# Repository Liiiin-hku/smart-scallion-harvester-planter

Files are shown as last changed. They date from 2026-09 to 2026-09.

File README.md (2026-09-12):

# 智能大葱收种一体机
# Smart Scallion Harvester–Planter

**机械结构设计作品集 · Mechanical Design Portfolio**

围绕大葱收获与种植作业的一体化机械方案，展示整机布局、型材车架、扶葱输送、弹簧张紧、翻土开沟及播种机构的 SOLIDWORKS 零件与装配设计。

A mechanical design concept integrating scallion harvesting and planting operations, with native SOLIDWORKS models covering the overall layout, profile frame, crop-guiding conveyors, spring tensioning, soil-working tools and planting mechanism.

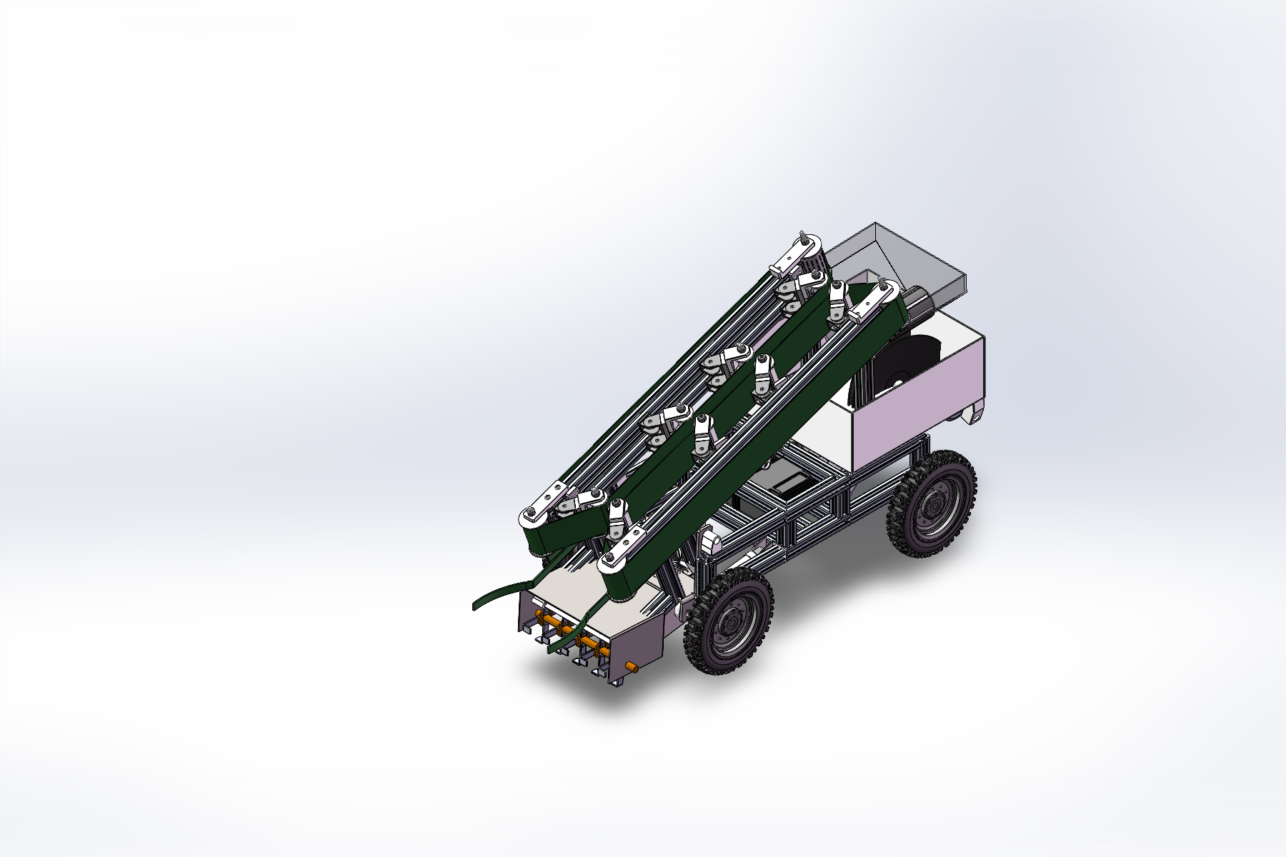
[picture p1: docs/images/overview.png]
整机等轴测视图 / Overall isometric view


> 图像直接导自本仓库模型的 SOLIDWORKS 视图。仓库定位为机械 CAD 设计展示；“智能”沿用项目概念名称，本次发布不包含控制程序、自动导航或田间试验数据。
>
> Images are exported directly from the repository's CAD models in SOLIDWORKS. This is a mechanical CAD portfolio. “Smart” is part of the project concept name; this release contains no control software, autonomous navigation implementation or field-test data.

**快速入口 / Quick links:** [机构详解 / Design walkthrough](docs/mechanical-design.md) · [模型打开指南 / Model guide](docs/model-guide.md) · [文件清单 / Inventory](docs/model-inventory.csv) · [核验记录 / Verification](docs/verification.md)

## 中文介绍

### 项目背景与方案

本项目围绕大葱收获、输送收集和种植相关作业，建立了一套共用移动底盘的机械结构方案。设计以型材车架为承载基础，将倾斜布置的收割输送组件、收集装置、翻土组件和播种组件整合到同一总装中，便于考察各机构的空间关系与安装接口。

机械设计重点在于作物流转路径与结构布置的协调：前端扶葱件与松土铲刀对应作物导入和根部松土位置；两侧输送带及导向滚轮形成向上输送通道；轴固定座、可调座、弹簧座和铰链构成滚轮支承与张紧调节结构；车架上的气缸和安装座提供作业组件的连接与调节接口。播种侧包含储存箱、播苗盘、圆盘、支撑型材及负重轮，翻土侧包含轴、翻土件、开沟件及起垄件。

最终交付是一套可查看整机及主要子机构的三维 CAD 模型，并保留 STEP 交换文件和已有工程图。设计意图依据实际零件、装配关系与可见几何说明；夹持力、张紧力、播种间距、工作效率及土壤适应性尚无本仓库内的试验数据支持。

### 建议技术读者重点查看

| 设计主题 | 模型中的具体内容 | 查看入口 |
| --- | --- | --- |
| 整机与承载结构 | 四轮布置、型材车架、横梁及多个机构安装位置 | `大葱收割机.SLDASM`、`车架.SLDPRT` |
| 扶葱与输送 | 扶葱/镜向扶葱、两侧倾斜输送带、多个导向滚轮、清土刷轮、松土铲刀 | `收割部分.SLDASM` |
| 滚轮支承与张紧 | 轴固定座、可调座、弹簧与弹簧座、活动铰链 | `输送带导向轮*.SLDASM` |
| 播种机构 | 储存箱、播苗盘、圆盘、支撑件、负重轮 | `播种部分.SLDASM` |
| 土壤作业机构 | 翻土、开沟、起垄件与共用轴的布置 | `翻土.SLDASM` |
| 装配接口 | 气缸及其安装座、轮组、轴承与标准紧固件 | 总装及配套子目录 |

## English overview

### Context and mechanical concept

This project develops a shared mobile platform for a scallion harvesting and planting concept. A frame built from structural profiles supports an inclined harvesting/conveying assembly, a collection unit, a soil-working assembly and a planting assembly. The CAD package lets reviewers examine how these mechanisms fit together and connect to the chassis.

The main design theme is the coordination of the crop path and mechanical layout. Front crop guides and soil-loosening blades define the entry region. Paired inclined belts and guide rollers form an upward conveying path. Shaft supports, adjustable mounts, spring seats and hinges form the roller-support and tensioning arrangement. Pneumatic cylinders and their mounting brackets provide mechanical connection and adjustment interfaces. The planting assembly includes a storage hopper, a planting drum/disc arrangement, supporting profiles and support wheels. The soil-working assembly includes a shaft with tilling, furrow-opening and ridging elements.

The deliverable is a three-dimensional CAD package for reviewing the complete machine and its main mechanisms, together with existing STEP exchange files and engineering drawings. Functional descriptions express design intent inferred from the actual parts, assembly relationships and visible geometry. Grip force, belt tension, planting spacing, throughput and soil performance have not been established by test data in this repository.

### Suggested technical review

Start with the overall layout and chassis interfaces, then inspect the crop-guiding conveyors, roller support and spring tensioning details. Continue with the planting and soil-working assemblies. The [illustrated walkthrough](docs/mechanical-design.md) maps these topics to exact filenames and explains the observed features in both languages.

## 获取与打开 / Download and open

1. 下载仓库完整 ZIP 并全部解压，或使用下方 Git 命令。Download and extract the entire repository ZIP, or clone it using the command below.
2. 用 SOLIDWORKS 打开 `cad/大葱收种一体机/大葱收割机.SLDASM`。Open this file as the main assembly in SOLIDWORKS.
3. 保留模型目录内的文件名和子目录。需要通用格式时可打开同目录的 `大葱收割机.STEP`。Preserve all filenames and subfolders. Use the existing `大葱收割机.STEP` for neutral-format viewing.

```bash
git clone https://github.com/Liiiin-hku/smart-scallion-harvester-planter.git
```

原模型目录完整保留，共 **217 个文件**：**86 个零件、18 个装配体、3 个工程图、110 个 STEP 文件**，合计 **221,436,406 字节（约 211.18 MiB）**。无需 Git LFS。文件数量不等于装配中的组件实例数量。

The original CAD directory is preserved with **217 files: 86 parts, 18 assemblies, 3 drawings and 110 STEP files**, totaling **221,436,406 bytes (approximately 211.18 MiB)**. Git LFS is not required. File counts differ from component-instance counts in an assembly.

## 版本与查看状态 / Version and viewing status

已在 **SOLIDWORKS 2025 SP3.0** 中只读打开总装与主要子机构并导出展示图。当前总装配置读取到 **346 个组件实例**，均为完全解析状态；其中 2 个实例来自同一个内嵌虚拟零件。总装引用链中的外部模型均位于本包内。

The main assembly and selected mechanisms were opened read-only in **SOLIDWORKS 2025 SP3.0** and used to export the illustrations. The active top-level configuration contains **346 fully resolved component instances**, including two instances of one embedded virtual part. External models in the main assembly's dependency chain resolve within this package.

两个历史工程图及八个镜向铰链装配存在缺失引用，详见[模型指南](docs/model-guide.md#known-reference-gaps)。模型内容未作修复、改名、格式升级或重新保存。已有 STEP 文件未重新生成，不承诺与原生模型逐实体一致。

Two historical drawings and eight mirrored-hinge assemblies have missing references, detailed in the [model guide](docs/model-guide.md#known-reference-gaps). Native CAD content has not been repaired, renamed, upgraded or resaved. Existing STEP files have not been regenerated or checked for entity-by-entity equivalence with the native models.

## 仓库结构 / Repository structure

```text
.
├── README.md                    # 中英文项目介绍 / Bilingual introduction
├── LICENSE                      # CERN-OHL-P-2.0
├── NOTICE.md                    # 许可范围与来源说明 / Scope and provenance
├── cad/
│   └── 大葱收种一体机/           # 原文件名、目录及内容 / Preserved CAD package
│       ├── 大葱收割机.SLDASM     # 总装入口 / Main assembly
│       ├── 大葱收割机.STEP       # 原有交换模型 / Existing neutral model
│       ├── 标件/                # 标准件与铰链 / Hardware and hinges
│       ├── 轮子/                # 轮组 / Wheel assembly
│       └── 不锈钢迷你型CTMA系列气缸[…]/  # 原气缸目录 / Original cylinder folder
└── docs/
    ├── images/                  # 原模型视图 / Direct CAD view exports
    ├── mechanical-design.md     # 机构详解 / Design walkthrough
    ├── model-guide.md           # 打开方法与历史引用问题 / Viewing guide
    ├── verification.md          # 核验范围 / Verification scope
    ├── dependency-audit.json    # 装配/工程图引用清单 / Dependency audit
    ├── model-inventory.csv      # 全部模型清单与哈希 / Inventory with hashes
    └── SHA256SUMS.txt           # 模型完整性校验 / CAD integrity checksums
```

## 开源许可 / Open-source licence

仓库所有者有权许可的原创机械设计贡献及本仓库项目文档采用 **[CERN Open Hardware Licence v2 — Permissive](LICENSE)**。标准件、轮组和供应商型气缸等模型不因本次整理而被主张为原创；其既有权利与适用条款保持不变。具体范围见 [NOTICE.md](NOTICE.md)。

Original mechanical-design contributions licensable by the repository owner and the accompanying project documentation are released under **[CERN Open Hardware Licence v2 — Permissive](LICENSE)**. Standard hardware, wheel models and supplier-style pneumatic components are not claimed as original work through this publication; existing rights and applicable terms remain unchanged. See [NOTICE.md](NOTICE.md) for scope.

维护者 / Maintainer: [Liiiin-hku](https://github.com/Liiiin-hku)

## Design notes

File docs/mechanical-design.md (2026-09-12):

# 机械结构详解 / Mechanical design walkthrough

[返回项目首页 / Back to project](../README.md)

以下说明来自总装、主要子装配、零件名称与实际 SOLIDWORKS 视图。关于作业功能的解释属于机械设计意图，不能替代运动分析、强度计算或样机测试。

This walkthrough is grounded in the main assembly, selected subassemblies, part names and direct SOLIDWORKS views. Explanations of operating functions describe mechanical intent; they do not replace motion analysis, structural calculations or prototype testing.

## 1. 整机布局与型材车架 / Overall layout and profile frame

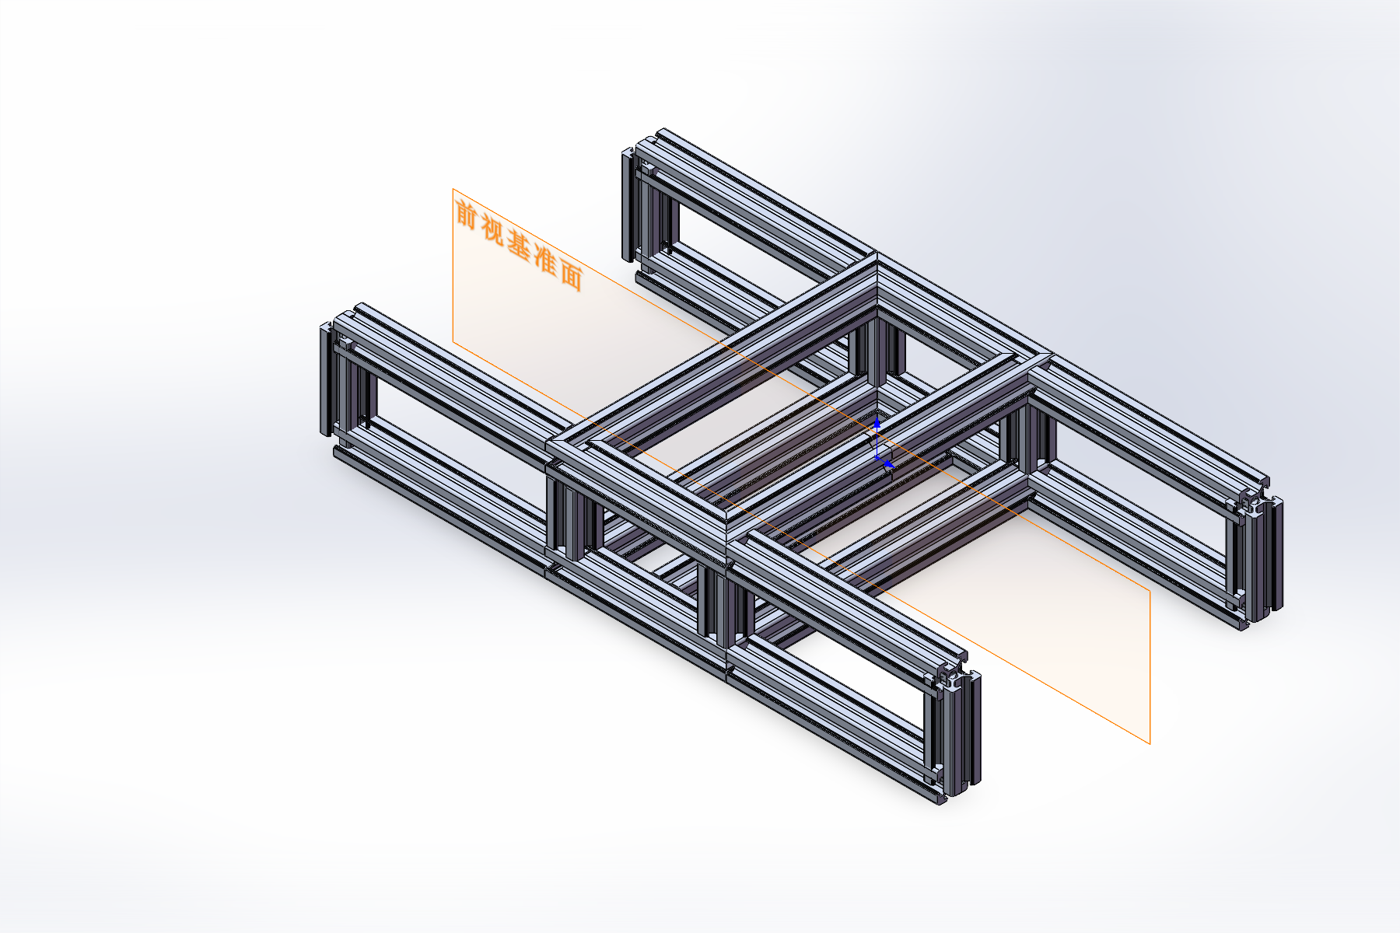
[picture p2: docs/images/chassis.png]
车架 / Chassis


入口：`大葱收割机.SLDASM`、`车架.SLDPRT`、`轮子/23. Tyre Sub Assembly.SLDASM`。

车架由纵向型材、横梁、竖向连接段与两侧外伸支承位置构成。总装中布置四个轮组，并通过车架及气缸安装座连接上方输送机构和其他作业部件。该模型适合讨论梁件布局、机构支承位置、安装孔/连接件的可接近性，以及各子机构与底盘的空间关系。具体型材材料、承载能力与安全系数需要材料定义和工况计算支持。

The chassis combines longitudinal profiles, cross-members, vertical connections and lateral support locations. Four wheel assemblies are present in the overall assembly. Frame and cylinder brackets connect the elevated conveyor structure and the other working modules. The model supports discussion of beam layout, support locations, fastener access and packaging around the chassis. Material properties, load capacity and safety factors require separate evidence.

## 2. 扶葱、松土与倾斜输送 / Crop guiding, soil loosening and conveying

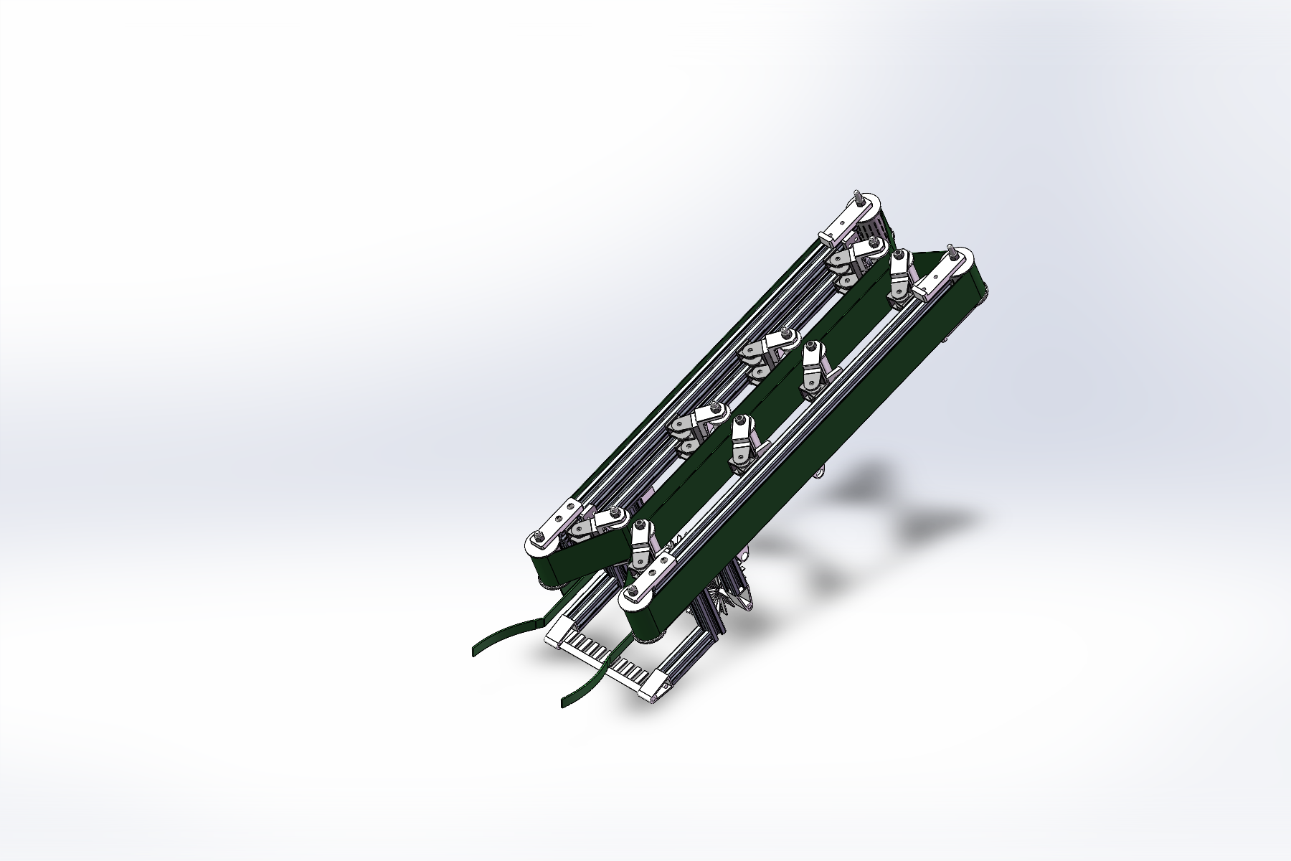
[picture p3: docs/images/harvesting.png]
收割输送组件 / Harvesting and conveying assembly


入口：`收割部分.SLDASM`。主要零件包括 `扶葱.SLDPRT`、`镜向扶葱.SLDPRT`、`松土铲刀.SLDPRT`、`输送带.SLDPRT`、`清土刷轮.SLDPRT` 及相应型材支撑。

前端成对导向件形成作物进入的位置，两侧输送带沿倾斜型材布置，多组滚轮沿输送路径分布。下方的松土铲刀和刷轮对应松土与清土设计位置。结合后部收集装置，可以理解其将作物导入、向上输送再收集的设计路径。输送方向及夹持/清土效果需由后续驱动布置、转速与作物试验确认。

Paired front guides define the crop-entry region. Two belts run along inclined supporting profiles, with multiple rollers distributed along the conveying path. Soil-loosening blades and cleaning rollers occupy the lower working region. Together with the collection unit, this suggests a crop-guiding, upward-conveying and collection path. Actual belt direction, gripping behaviour and cleaning performance require drive specifications and crop tests.

## 3. 滚轮支承与弹簧张紧 / Roller support and spring tensioning

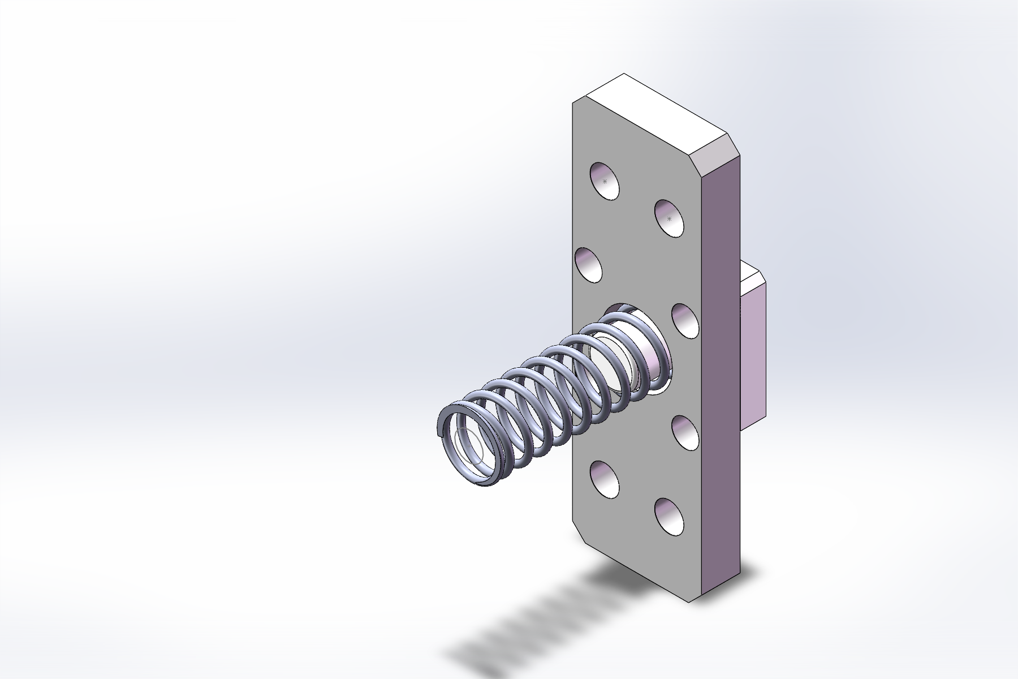
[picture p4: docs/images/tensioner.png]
张紧子装配 / Tensioning subassembly


入口：`输送带导向轮.SLDASM`、`输送带导向轮2.SLDASM`、`输送带导向轮2张紧.SLDASM`。

原模型把滚轮轴及轴承、轴固定座、调节座和弹簧座等拆分为可独立查看的零件/子装配。图示张紧子装配中可见安装板、支承件和螺旋弹簧；在收割总成中，可进一步查看它与滚轮和活动铰链之间的连接。其结构意图是为输送带滚轮提供支承和弹性调节，实际预紧量、行程、弹簧刚度及张紧力未在此次展示中定量验证。

Roller shafts, bearings, fixed and adjustable mounts, and spring seats are separated into inspectable parts and subassemblies. The illustrated tensioning subassembly contains a mounting plate, a support element and a helical spring. The harvesting assembly shows how these elements connect to the rollers and hinges. The arrangement suggests roller support with compliant adjustment; preload, stroke, spring rate and belt tension have not been quantitatively verified here.

## 4. 播种与支承组件 / Planting and support assembly

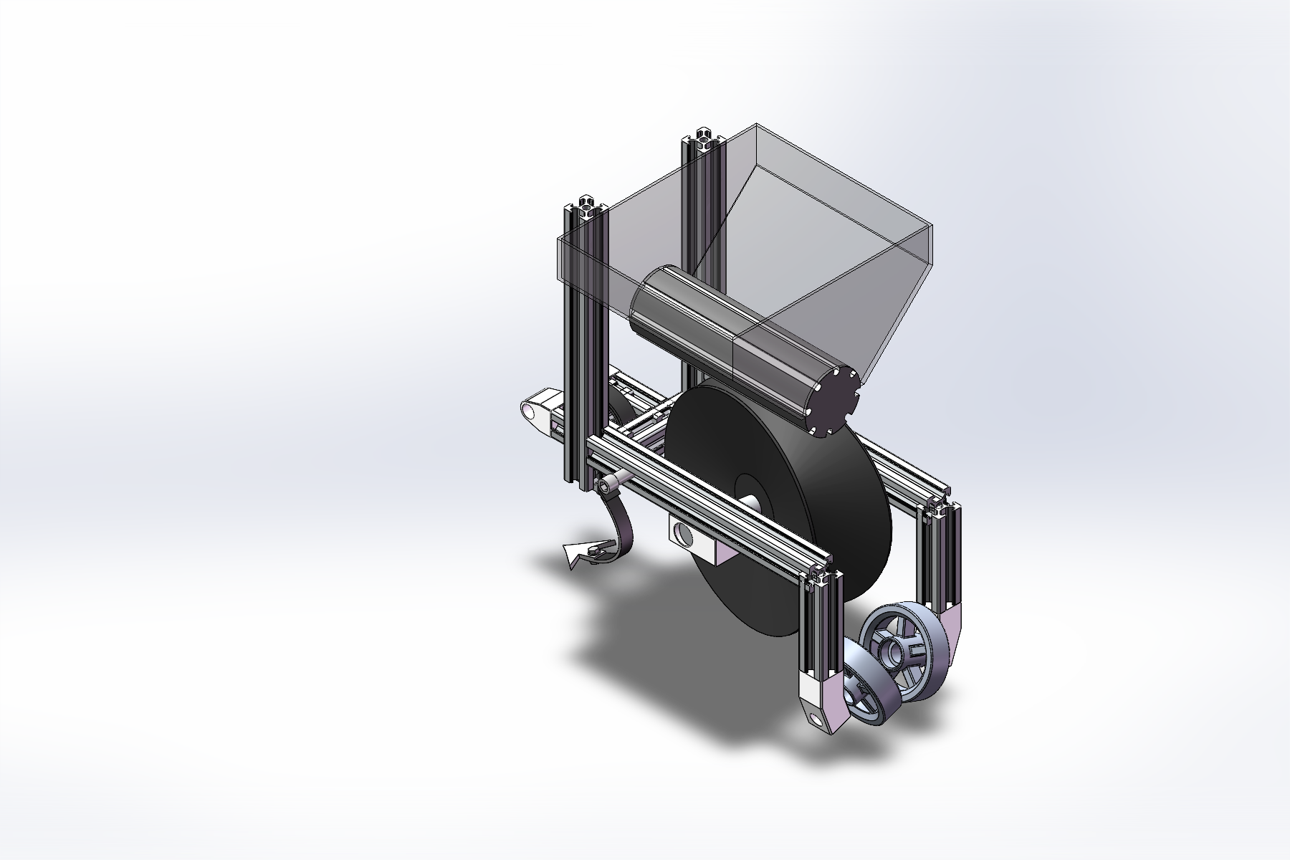
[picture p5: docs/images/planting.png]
播种组件 / Planting assembly


入口：`播种部分.SLDASM`。主要零件包括 `储存箱子.SLDPRT`、`储存箱子支撑.SLDPRT`、`播苗盘.SLDPRT`、`盘.SLDPRT`、`负重轮.SLDPRT`、`负重轮座.SLDPRT`、`Spike Gribe.SLDPRT`。

模型可见上方储存箱、水平圆筒形播苗件、竖向圆盘、型材支撑以及下部支承轮。通过这些部件，可讨论储存/供料位置、播苗部件的安装方向与对地支承。原文件名称采用“播种/播苗”，本仓库沿用这一称呼；仅凭静态 CAD 不把它进一步定性为已验证的精量播种或自动移栽机构。

Visible features include an upper storage hopper, a horizontal cylindrical planting element, a vertical disc, supporting profiles and lower support wheels. These allow reviewers to examine storage/feed positioning, mounting orientation and ground-support geometry. The original files use planting/seedling-related names. Static CAD alone does not establish precision seeding or automated transplanting performance.

## 5. 翻土、开沟与起垄 / Tilling, furrow opening and ridging

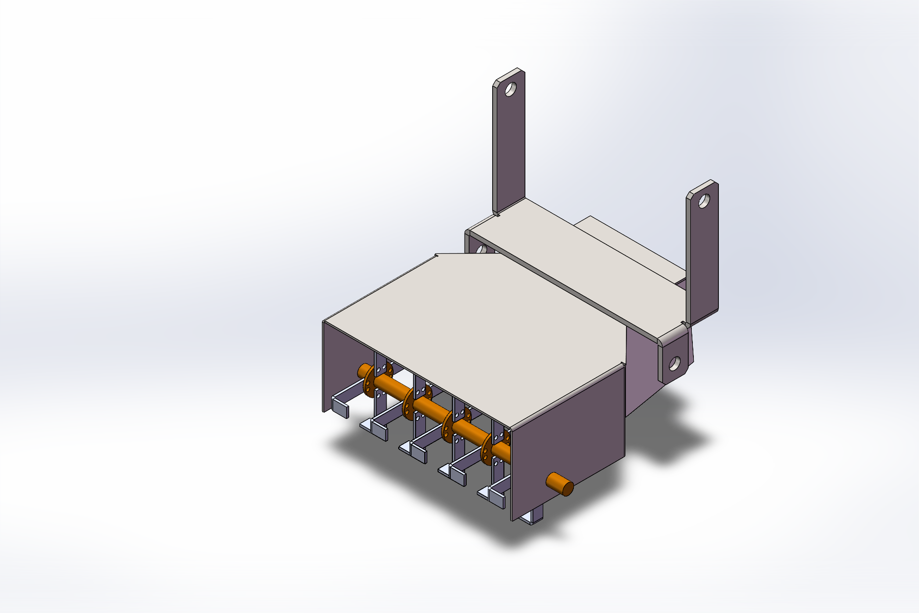
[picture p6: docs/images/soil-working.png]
土壤作业组件 / Soil-working assembly


入口：`翻土.SLDASM`。主要零件包括 `翻土.SLDPRT`、`开沟.SLDPRT`、`起垄.SLDPRT`、`起垄座.SLDPRT`、`轴.SLDPRT`。

图中可见板件围合结构、带多组重复作业件的共用轴，以及上部安装连接板。该模块集中体现了轴系布置、多个作业件的轴向排列和模块与整机的连接方式。零件名称对应翻土、开沟与起垄功能；入土深度、土壤阻力、堵塞风险及各工序能否连续协同仍需工况分析与试验。

The assembly shows a plate enclosure, a common shaft carrying repeated working elements and upper mounting plates. It illustrates shaft layout, axial spacing of tools and attachment to the overall machine. Part names correspond to tilling, furrow opening and ridging. Working depth, soil resistance, clogging and coordination between operations require further analysis and testing.

## 6. 气缸接口与标准件集成 / Cylinder interfaces and standard components

总装包含四个 CTMA 系列气缸实例、多个气缸座与后铰固定架。配套目录保留了气缸、杆端、紧固件、轴承、铰链和轮组模型。它们用于展示结构接口、连接关系和装配空间；目录中的供应商型号及标准代号不是本项目对其原创性的声明，也不能替代采购规格或选型计算。

The main assembly contains four CTMA-series cylinder instances, several mounting brackets and rear clevis supports. Supporting directories retain cylinder, rod-end, fastener, bearing, hinge and wheel models. They document mechanical interfaces and assembly space. Supplier-style identifiers and standard designations do not imply project authorship of those components or replace procurement specifications and sizing calculations.

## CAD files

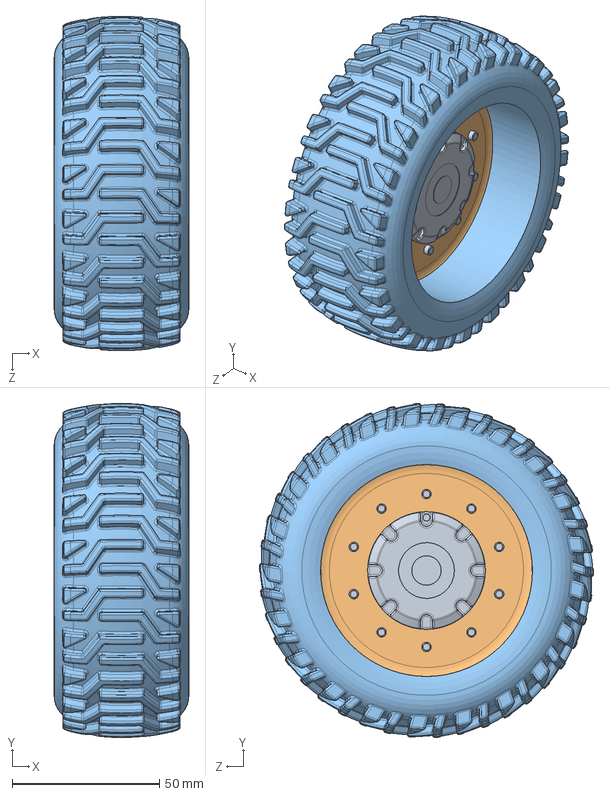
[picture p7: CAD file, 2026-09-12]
cad/大葱收种一体机/轮子/23. Tyre Sub Assembly.SLDASM
45.8 x 113.6 x 113.7 mm
19.AXLE
20.RIM
21. TYRE

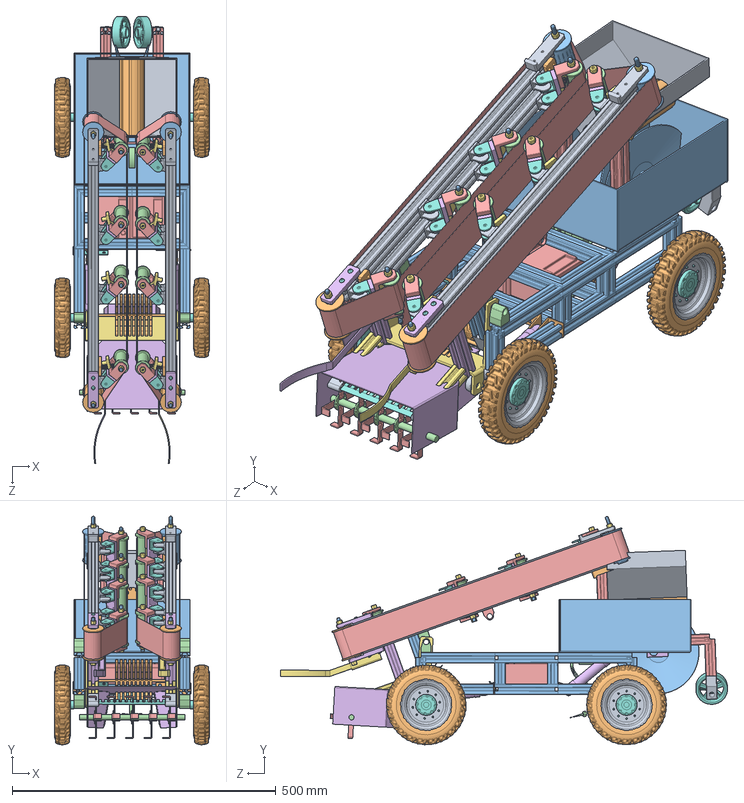
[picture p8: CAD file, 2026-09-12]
cad/大葱收种一体机/大葱收割机.SLDASM
294.7 x 433.5 x 847.6 mm
输送带型材 x 4
输送带导向滚 x 2
输送带导向滚轴 x 12
GB╱T 276-2013[一面带密封圈（非接触式）的深沟球轴承[60000-RZ]619／6-RZ] x 20
输送带支撑型材 x 4
传送带轴固定座 x 4
GB╱T 6186-2000[2型全金属六角锁紧螺母 9级M6] x 24
GB╱T 70.2-2015[内六角平圆头螺钉M4×12] x 8
传送带轴固定调节座 x 2
传送带轴固定调节电机座 x 2
输送带导向滚 动力 x 2
输送带导向滚2 x 8
传送带轴固定座2 x 16
输送带导向滚2固定亚克力板 x 8
弹簧座2 x 8
_CT1-20-2020.step x 16
_CT2-20-2020.step x 16
弹簧座亚克力 x 4
弹簧座 x 4
1X10X30 x 4
输送带 x 2
松土型材支架 x 2
松土型材支架2 x 2
松土铲刀
松土铲刀固定 x 4
清土刷轮
清土轮支架支撑型材2 x 2
气缸座 x 2
气缸座 3 x 2
扶葱
镜向扶葱
19.AXLE x 4
20.RIM x 4
21. TYRE x 4
车架
气缸座2 x 10
电源 x 2
不锈钢迷你型CTMA系列气缸[CTMA-16x25-S-CA-SDB]_16缸体 x 4
不锈钢迷你型CTMA系列气缸[CTMA-16x25-S-CA-SDB]_16活塞杆 x 4
杆端F-M8X125U x 4
SDB x 4
收集装置
轴
翻土 x 36
起垄
起垄座
开沟
储存箱子
盘
播苗盘 x 2
Spike Gribe
储存箱子支撑
固定座 x 2
特殊螺钉 小径内六角圆柱头螺钉[PSGS-M8-30-B]
负重轮 x 2
负重轮座 x 2

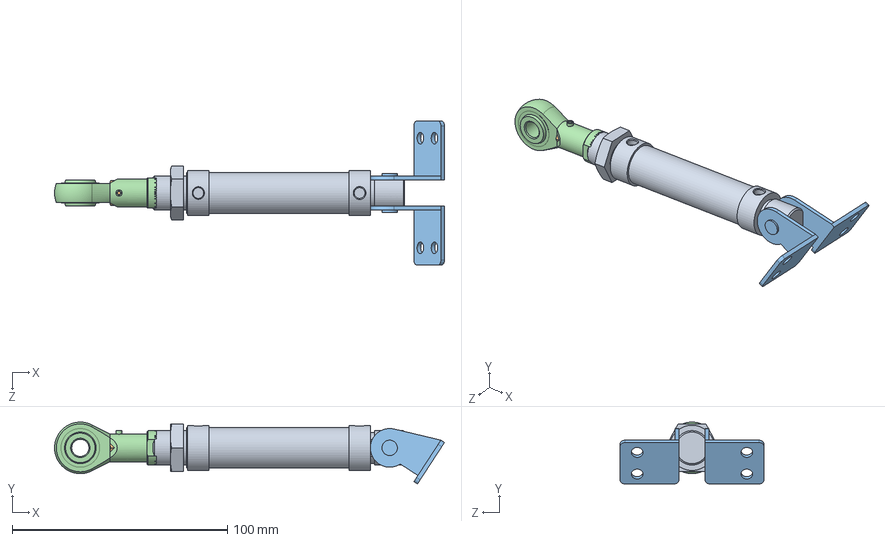
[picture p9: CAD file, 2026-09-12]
cad/大葱收种一体机/不锈钢迷你型CTMA系列气缸[CTMA-16x25-S-CA-SDB]/不锈钢迷你型CTMA系列气缸[CTMA-16x25-S-CA-SDB].sldasm
181.4 x 28.8 x 67.0 mm
不锈钢迷你型CTMA系列气缸[CTMA-16x25-S-CA-SDB]_16缸体
不锈钢迷你型CTMA系列气缸[CTMA-16x25-S-CA-SDB]_16活塞杆
不锈钢迷你型CTMA系列气缸[CTMA-16x25-S-CA-SDB]_SDB
杆端F-M8X125U

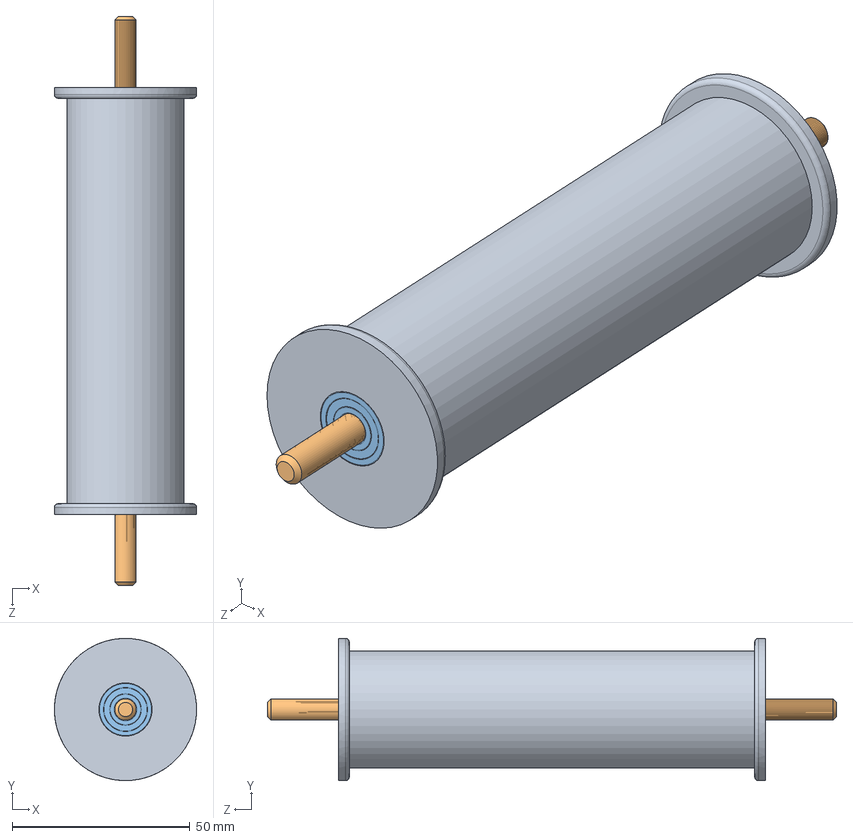
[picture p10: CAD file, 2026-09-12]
cad/大葱收种一体机/输送带导向轮.SLDASM
40.0 x 40.0 x 160.0 mm
输送带导向滚
输送带导向滚轴
GB╱T 276-2013[一面带密封圈（非接触式）的深沟球轴承[60000-RZ]619／6-RZ] x 2

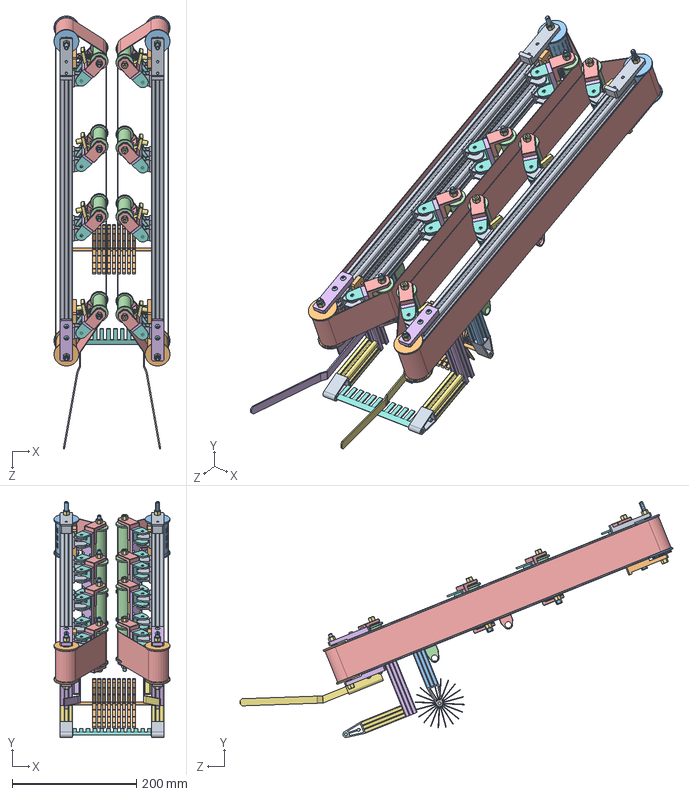
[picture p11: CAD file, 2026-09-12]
cad/大葱收种一体机/收割部分.SLDASM
186.8 x 380.5 x 697.7 mm
输送带型材 x 4
输送带导向滚 x 2
输送带导向滚轴 x 12
GB╱T 276-2013[一面带密封圈（非接触式）的深沟球轴承[60000-RZ]619／6-RZ] x 20
输送带支撑型材 x 4
传送带轴固定座 x 4
GB╱T 6186-2000[2型全金属六角锁紧螺母 9级M6] x 24
GB╱T 70.2-2015[内六角平圆头螺钉M4×12] x 8
传送带轴固定调节座 x 2
传送带轴固定调节电机座 x 2
输送带导向滚 动力 x 2
输送带导向滚2 x 8
传送带轴固定座2 x 16
输送带导向滚2固定亚克力板 x 8
弹簧座2 x 8
_CT1-20-2020.step x 16
_CT2-20-2020.step x 16
弹簧座亚克力 x 4
弹簧座 x 4
1X10X30 x 4
输送带 x 2
松土型材支架 x 2
松土型材支架2 x 2
松土铲刀
松土铲刀固定 x 4
清土刷轮
清土轮支架支撑型材2 x 2
气缸座 x 2
气缸座 3 x 2
扶葱
镜向扶葱

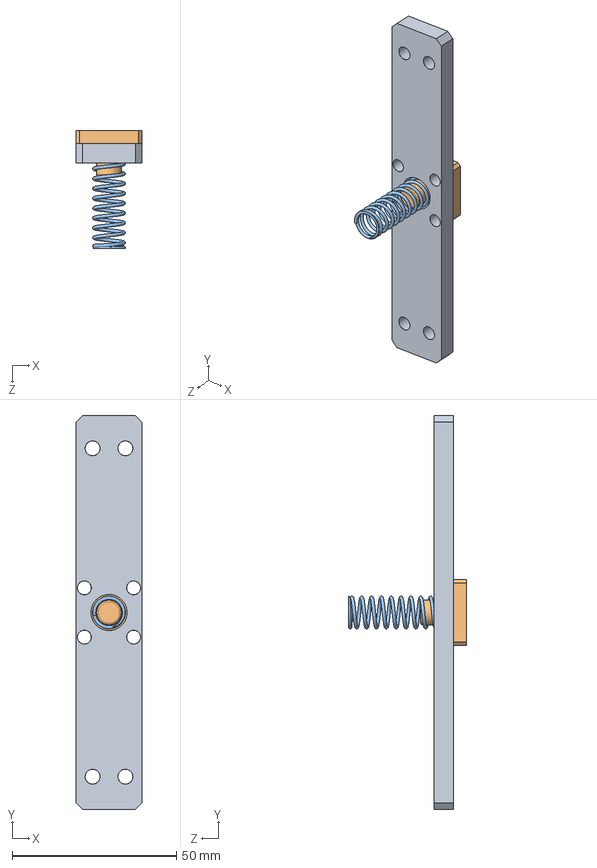
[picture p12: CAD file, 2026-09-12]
cad/大葱收种一体机/输送带导向轮2张紧.SLDASM
20.0 x 120.0 x 36.0 mm
弹簧座亚克力
弹簧座
1X10X30

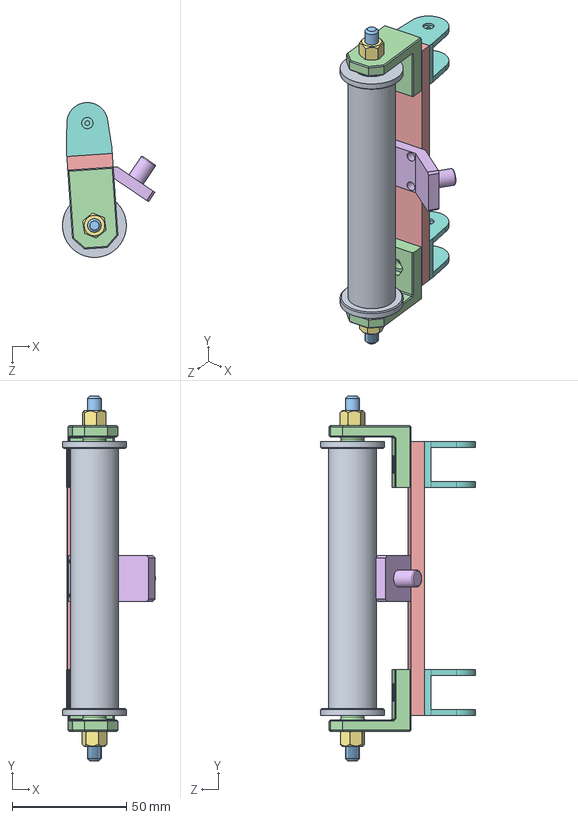
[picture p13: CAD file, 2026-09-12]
cad/大葱收种一体机/输送带导向轮2.SLDASM
40.8 x 160.0 x 67.9 mm
输送带导向滚2
GB╱T 276-2013[一面带密封圈（非接触式）的深沟球轴承[60000-RZ]619／6-RZ] x 2
输送带导向滚轴
传送带轴固定座2 x 2
输送带导向滚2固定亚克力板
弹簧座2
GB╱T 6186-2000[2型全金属六角锁紧螺母 9级M6] x 2
_CT1-20-2020.step x 2

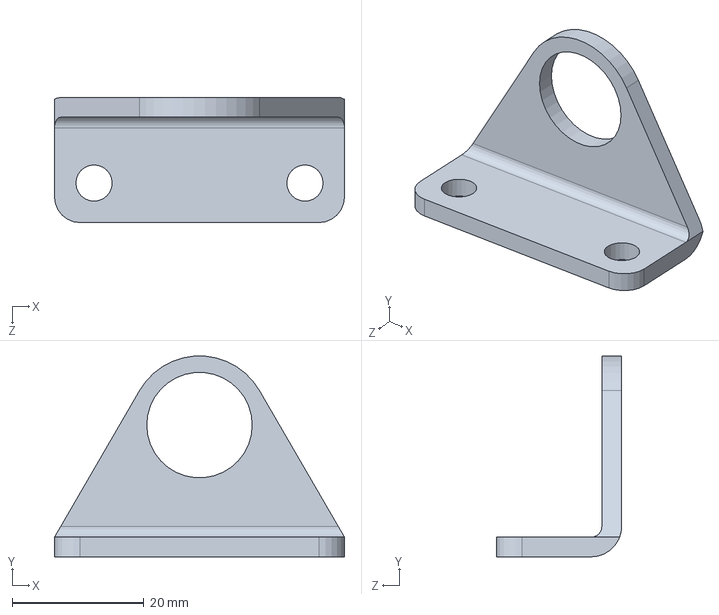
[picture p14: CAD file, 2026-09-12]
cad/大葱收种一体机/不锈钢迷你型CTMA系列气缸[CTMA-16x25-S-CA-SDB]/LB.SLDPRT
44.0 x 30.5 x 19.0 mm

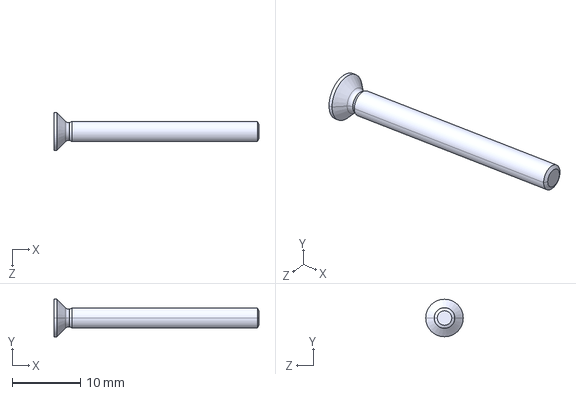
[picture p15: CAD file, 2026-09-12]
cad/大葱收种一体机/标件/GB╱T 819.1-2016[十字槽沉头螺钉M3×30].step
30.0 x 5.50 x 5.50 mm

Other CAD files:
cad/大葱收种一体机/标件/镜向活动铰链[CT-20-2020].step2.SLDASM
cad/大葱收种一体机/标件/活动铰链[CT-20-2020].step.SLDASM
cad/大葱收种一体机/标件/镜向活动铰链[CT-20-2020].step6.SLDASM
cad/大葱收种一体机/标件/镜向活动铰链[CT-20-2020].step4.SLDASM
cad/大葱收种一体机/标件/镜向活动铰链[CT-20-2020].step7.SLDASM
cad/大葱收种一体机/标件/镜向活动铰链[CT-20-2020].step5.SLDASM
cad/大葱收种一体机/标件/镜向活动铰链[CT-20-2020].step3.SLDASM
cad/大葱收种一体机/标件/镜向活动铰链[CT-20-2020].step1.SLDASM
cad/大葱收种一体机/标件/镜向活动铰链[CT-20-2020].step.SLDASM
cad/大葱收种一体机/11x5t5.step
cad/大葱收种一体机/16活塞杆.step
cad/大葱收种一体机/16缸体.step
cad/大葱收种一体机/17x26t5.step
cad/大葱收种一体机/19.AXLE.step
cad/大葱收种一体机/1X10X30.SLDPRT
cad/大葱收种一体机/1X10X30.step
cad/大葱收种一体机/1X10X50.SLDPRT
cad/大葱收种一体机/1X10X50.step
cad/大葱收种一体机/20.RIM.step
cad/大葱收种一体机/20系列2020压铸角铝[CB-20-2020].step
cad/大葱收种一体机/21. TYRE.step
cad/大葱收种一体机/FA.step
cad/大葱收种一体机/GB╱T 276-2013[一面带密封圈（非接触式）的深沟球轴承[60000-RZ]619／6-RZ].step
cad/大葱收种一体机/GB╱T 6186-2000[2型全金属六角锁紧螺母 9级M5].step
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

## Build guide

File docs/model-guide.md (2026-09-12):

# 模型查看指南 / Model viewing guide

[项目首页 / Project](../README.md) · [机构详解 / Walkthrough](mechanical-design.md)

## 推荐查看顺序 / Suggested sequence

| 顺序 / Order | 文件 / File | 用途 / Purpose |
| --- | --- | --- |
| 1 | `cad/大葱收种一体机/大葱收割机.SLDASM` | 总装与空间布局 / Main assembly and layout |
| 2 | 同目录 / Same directory: `收割部分.SLDASM` | 扶葱、松土、输送及张紧 / Guiding, loosening, conveying and tensioning |
| 3 | `播种部分.SLDASM`、`翻土.SLDASM` | 播种与土壤作业 / Planting and soil working |
| 4 | `车架.SLDPRT`、`输送带导向轮2张紧.SLDASM` | 支承及局部结构 / Frame and mechanism detail |
| 5 | `大葱收割机.SLDDRW` | 已有整机工程图 / Existing overall drawing |

## 下载与引用 / Download and references

完整下载仓库并解压后再打开。不要只下载一个 `.SLDASM`，也不要把标准件与子装配从原目录中移走。模型包内部目录和文件名保持原样，只有外层增加 `cad/` 归档目录。

Download and extract the complete repository. A single `.SLDASM` file is insufficient. Keep hardware and subassembly files in their original folders. Internal filenames and folder relationships are preserved; only the outer `cad/` directory has been added for repository organization.

若 SOLIDWORKS 询问引用位置，先指向 `cad/大葱收种一体机/`，再根据文件名定位 `标件/`、`轮子/` 或原气缸子目录。可以只读查看，避免软件版本转换或重建操作写回文件。原生文件的保存版本未逐个确认；本次实测查看环境为 SOLIDWORKS 2025 SP3.0。已有总装 STEP 头部标识为 SolidWorks 2022 / AP214，但这不证明所有原生文件都能用 2022 打开。

If SOLIDWORKS asks for a reference location, point it to the model directory and then the appropriate hardware, wheel or cylinder subfolder. Read-only viewing avoids writing version conversions or rebuild changes back to the files. Native save versions have not been verified individually. The viewing environment used for this release was SOLIDWORKS 2025 SP3.0. The existing main STEP header identifies SolidWorks 2022 / AP214; this does not prove that every native file can be opened in 2022.

## STEP 与工程图 / STEP files and drawings

`大葱收割机.STEP` 是已有整机交换模型，适合支持 STEP 的 CAD 查看工具。STEP 不保留与原生 SOLIDWORKS 相同的参数化历史和配合编辑体验。保留的 110 个 STEP 中包含不同目录下的同名文件，未擅自去重；它们是原始交付的一部分。三张原有工程图全部保留，但其中两张有下列历史引用缺口。

The existing `大葱收割机.STEP` is a neutral-format overall model for compatible CAD viewers. It does not offer the same parametric history and mate-editing workflow as native SOLIDWORKS. All 110 existing STEP files are retained, including same-named files in different folders; none were deduplicated. All three original drawings are included, with the historical reference gaps below.

## 已知引用缺口 / Known reference gaps

| 受影响文件 / Affected files | 当前文件夹未提供的引用 / Referenced files not supplied |
| --- | --- |
| `履带原版.SLDDRW` | `履带原版.SLDASM` |
| `拆解.SLDDRW` | `拆解.SLDASM` |
| `标件/镜向活动铰链[CT-20-2020].step.SLDASM` 及 / and `.step1.SLDASM` 至 / through `.step7.SLDASM`，共 8 个 / 8 files | `镜向_CT1-20-2020.step.SLDPRT`、`镜向_CT2-20-2020.step.SLDPRT` |

这些文件按原样保留，不应把其独立重建完整性视为已验证。当前总装加载的是可解析的非镜向铰链链路，上述缺口未出现在总装的实际引用链中。不要将缺失的镜向件直接替换为非镜向件；几何与装配关系可能不同。`履带原版.SLDDRW` 的历史文件名也不代表当前四轮总装采用履带结构。

These files are retained unchanged, and their standalone rebuild completeness is not verified. The active main assembly resolves the non-mirrored hinge chain; these gaps are outside its inspected dependency chain. Do not substitute non-mirrored parts for missing mirrored parts without design review. The historical tracked-version drawing filename does not describe the four-wheel layout of the current main assembly.

`零件5^收割部分.SLDPRT` 为 `收割部分.SLDASM` 内嵌的虚拟零件，在总装中有两个实例。SOLIDWORKS 会把它临时展开到运行时缓存，它不是需要另外上传的外部零件。引用清单以 `embedded_virtual: true` 标记该项。

`零件5^收割部分.SLDPRT` is a virtual part embedded in `收割部分.SLDASM`, with two instances in the main assembly. SOLIDWORKS temporarily expands it into a runtime cache; no separate external file needs uploading. The audit marks it as `embedded_virtual: true`.

## 保留原模型状态 / Preserved model state

本次仅检查加载、引用与可见结构，没有执行全模型重建、配合修复、干涉检查、运动仿真、有限元分析或制造验收。需要工程修改时，请在副本或独立分支进行，并记录变化；本次发布的模型与用户提供文件逐字节一致。

This release checks loading, references and visible structure; it does not certify a full rebuild, mate repair, interference check, motion simulation, finite-element analysis or manufacturing readiness. Make engineering changes in a separate copy or branch and record them. Published CAD files are byte-for-byte identical to the supplied files.

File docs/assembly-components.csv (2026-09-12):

instance | model | configuration | fully_resolved | embedded_virtual
23. Tyre Sub Assembly-1 | cad/大葱收种一体机/轮子/23. Tyre Sub Assembly.SLDASM | Default | True | False
23. Tyre Sub Assembly-1/19.AXLE-1 | cad/大葱收种一体机/轮子/19.AXLE.SLDPRT | Default | True | False
23. Tyre Sub Assembly-1/20.RIM-1 | cad/大葱收种一体机/轮子/20.RIM.SLDPRT | Default | True | False
23. Tyre Sub Assembly-1/21. TYRE-1 | cad/大葱收种一体机/轮子/21. TYRE.SLDPRT | Default | True | False
23. Tyre Sub Assembly-3 | cad/大葱收种一体机/轮子/23. Tyre Sub Assembly.SLDASM | Default | True | False
23. Tyre Sub Assembly-3/19.AXLE-1 | cad/大葱收种一体机/轮子/19.AXLE.SLDPRT | Default | True | False
23. Tyre Sub Assembly-3/20.RIM-1 | cad/大葱收种一体机/轮子/20.RIM.SLDPRT | Default | True | False
23. Tyre Sub Assembly-3/21. TYRE-1 | cad/大葱收种一体机/轮子/21. TYRE.SLDPRT | Default | True | False
23. Tyre Sub Assembly-5 | cad/大葱收种一体机/轮子/23. Tyre Sub Assembly.SLDASM | Default | True | False
23. Tyre Sub Assembly-5/19.AXLE-1 | cad/大葱收种一体机/轮子/19.AXLE.SLDPRT | Default | True | False
23. Tyre Sub Assembly-5/20.RIM-1 | cad/大葱收种一体机/轮子/20.RIM.SLDPRT | Default | True | False
23. Tyre Sub Assembly-5/21. TYRE-1 | cad/大葱收种一体机/轮子/21. TYRE.SLDPRT | Default | True | False
23. Tyre Sub Assembly-6 | cad/大葱收种一体机/轮子/23. Tyre Sub Assembly.SLDASM | Default | True | False
23. Tyre Sub Assembly-6/19.AXLE-1 | cad/大葱收种一体机/轮子/19.AXLE.SLDPRT | Default | True | False
23. Tyre Sub Assembly-6/20.RIM-1 | cad/大葱收种一体机/轮子/20.RIM.SLDPRT | Default | True | False
23. Tyre Sub Assembly-6/21. TYRE-1 | cad/大葱收种一体机/轮子/21. TYRE.SLDPRT | Default | True | False
SDB-1 | cad/大葱收种一体机/不锈钢迷你型CTMA系列气缸[CTMA-16x25-S-CA-SDB]/SDB.SLDPRT | 后铰固定架 | True | False
SDB-2 | cad/大葱收种一体机/不锈钢迷你型CTMA系列气缸[CTMA-16x25-S-CA-SDB]/SDB.SLDPRT | 后铰固定架 | True | False
SDB-3 | cad/大葱收种一体机/不锈钢迷你型CTMA系列气缸[CTMA-16x25-S-CA-SDB]/SDB.SLDPRT | 后铰固定架 | True | False
SDB-4 | cad/大葱收种一体机/不锈钢迷你型CTMA系列气缸[CTMA-16x25-S-CA-SDB]/SDB.SLDPRT | 后铰固定架 | True | False
不锈钢迷你型CTMA系列气缸[CTMA-16x25-S-CA-SDB]-1 | cad/大葱收种一体机/不锈钢迷你型CTMA系列气缸[CTMA-16x25-S-CA-SDB]/不锈钢迷你型CTMA系列气缸[CTMA-16x25-S-CA-SDB].sldasm | CTMA-16x25-S-CA-SDB | True | False
不锈钢迷你型CTMA系列气缸[CTMA-16x25-S-CA-SDB]-1/不锈钢迷你型CTMA系列气缸[CTMA-16x25-S-CA-SDB]_16活塞杆-2 | cad/大葱收种一体机/不锈钢迷你型CTMA系列气缸[CTMA-16x25-S-CA-SDB]/不锈钢迷你型CTMA系列气缸[CTMA-16x25-S-CA-SDB]_16活塞杆.SLDPRT | 16 | True | False
不锈钢迷你型CTMA系列气缸[CTMA-16x25-S-CA-SDB]-1/不锈钢迷你型CTMA系列气缸[CTMA-16x25-S-CA-SDB]_16缸体-2 | cad/大葱收种一体机/不锈钢迷你型CTMA系列气缸[CTMA-16x25-S-CA-SDB]/不锈钢迷你型CTMA系列气缸[CTMA-16x25-S-CA-SDB]_16缸体.SLDPRT | 16 | True | False
不锈钢迷你型CTMA系列气缸[CTMA-16x25-S-CA-SDB]-1/不锈钢迷你型CTMA系列气缸[CTMA-16x25-S-CA-SDB]_SDB-1 | cad/大葱收种一体机/不锈钢迷你型CTMA系列气缸[CTMA-16x25-S-CA-SDB]/不锈钢迷你型CTMA系列气缸[CTMA-16x25-S-CA-SDB]_SDB.SLDPRT | 后铰固定架 | True | False
不锈钢迷你型CTMA系列气缸[CTMA-16x25-S-CA-SDB]-1/杆端F-M8X125U-1 | cad/大葱收种一体机/杆端F-M8X125U.SLDPRT | 默认 | True | False
不锈钢迷你型CTMA系列气缸[CTMA-16x25-S-CA-SDB]-2 | cad/大葱收种一体机/不锈钢迷你型CTMA系列气缸[CTMA-16x25-S-CA-SDB]/不锈钢迷你型CTMA系列气缸[CTMA-16x25-S-CA-SDB].sldasm | CTMA-16x25-S-CA-SDB | True | False
不锈钢迷你型CTMA系列气缸[CTMA-16x25-S-CA-SDB]-2/不锈钢迷你型CTMA系列气缸[CTMA-16x25-S-CA-SDB]_16活塞杆-2 | cad/大葱收种一体机/不锈钢迷你型CTMA系列气缸[CTMA-16x25-S-CA-SDB]/不锈钢迷你型CTMA系列气缸[CTMA-16x25-S-CA-SDB]_16活塞杆.SLDPRT | 16 | True | False
不锈钢迷你型CTMA系列气缸[CTMA-16x25-S-CA-SDB]-2/不锈钢迷你型CTMA系列气缸[CTMA-16x25-S-CA-SDB]_16缸体-2 | cad/大葱收种一体机/不锈钢迷你型CTMA系列气缸[CTMA-16x25-S-CA-SDB]/不锈钢迷你型CTMA系列气缸[CTMA-16x25-S-CA-SDB]_16缸体.SLDPRT | 16 | True | False
不锈钢迷你型CTMA系列气缸[CTMA-16x25-S-CA-SDB]-2/不锈钢迷你型CTMA系列气缸[CTMA-16x25-S-CA-SDB]_SDB-1 | cad/大葱收种一体机/不锈钢迷你型CTMA系列气缸[CTMA-16x25-S-CA-SDB]/不锈钢迷你型CTMA系列气缸[CTMA-16x25-S-CA-SDB]_SDB.SLDPRT | 后铰固定架 | True | False
不锈钢迷你型CTMA系列气缸[CTMA-16x25-S-CA-SDB]-2/杆端F-M8X125U-1 | cad/大葱收种一体机/杆端F-M8X125U.SLDPRT | 默认 | True | False
不锈钢迷你型CTMA系列气缸[CTMA-16x25-S-CA-SDB]-3 | cad/大葱收种一体机/不锈钢迷你型CTMA系列气缸[CTMA-16x25-S-CA-SDB]/不锈钢迷你型CTMA系列气缸[CTMA-16x25-S-CA-SDB].sldasm | CTMA-16x25-S-CA-SDB | True | False
不锈钢迷你型CTMA系列气缸[CTMA-16x25-S-CA-SDB]-3/不锈钢迷你型CTMA系列气缸[CTMA-16x25-S-CA-SDB]_16活塞杆-2 | cad/大葱收种一体机/不锈钢迷你型CTMA系列气缸[CTMA-16x25-S-CA-SDB]/不锈钢迷你型CTMA系列气缸[CTMA-16x25-S-CA-SDB]_16活塞杆.SLDPRT | 16 | True | False
不锈钢迷你型CTMA系列气缸[CTMA-16x25-S-CA-SDB]-3/不锈钢迷你型CTMA系列气缸[CTMA-16x25-S-CA-SDB]_16缸体-2 | cad/大葱收种一体机/不锈钢迷你型CTMA系列气缸[CTMA-16x25-S-CA-SDB]/不锈钢迷你型CTMA系列气缸[CTMA-16x25-S-CA-SDB]_16缸体.SLDPRT | 16 | True | False
不锈钢迷你型CTMA系列气缸[CTMA-16x25-S-CA-SDB]-3/不锈钢迷你型CTMA系列气缸[CTMA-16x25-S-CA-SDB]_SDB-1 | cad/大葱收种一体机/不锈钢迷你型CTMA系列气缸[CTMA-16x25-S-CA-SDB]/不锈钢迷你型CTMA系列气缸[CTMA-16x25-S-CA-SDB]_SDB.SLDPRT | 后铰固定架 | True | False
不锈钢迷你型CTMA系列气缸[CTMA-16x25-S-CA-SDB]-3/杆端F-M8X125U-1 | cad/大葱收种一体机/杆端F-M8X125U.SLDPRT | 默认 | True | False
不锈钢迷你型CTMA系列气缸[CTMA-16x25-S-CA-SDB]-4 | cad/大葱收种一体机/不锈钢迷你型CTMA系列气缸[CTMA-16x25-S-CA-SDB]/不锈钢迷你型CTMA系列气缸[CTMA-16x25-S-CA-SDB].sldasm | CTMA-16x25-S-CA-SDB | True | False
不锈钢迷你型CTMA系列气缸[CTMA-16x25-S-CA-SDB]-4/不锈钢迷你型CTMA系列气缸[CTMA-16x25-S-CA-SDB]_16活塞杆-2 | cad/大葱收种一体机/不锈钢迷你型CTMA系列气缸[CTMA-16x25-S-CA-SDB]/不锈钢迷你型CTMA系列气缸[CTMA-16x25-S-CA-SDB]_16活塞杆.SLDPRT | 16 | True | False
不锈钢迷你型CTMA系列气缸[CTMA-16x25-S-CA-SDB]-4/不锈钢迷你型CTMA系列气缸[CTMA-16x25-S-CA-SDB]_16缸体-2 | cad/大葱收种一体机/不锈钢迷你型CTMA系列气缸[CTMA-16x25-S-CA-SDB]/不锈钢迷你型CTMA系列气缸[CTMA-16x25-S-CA-SDB]_16缸体.SLDPRT | 16 | True | False
不锈钢迷你型CTMA系列气缸[CTMA-16x25-S-CA-SDB]-4/不锈钢迷你型CTMA系列气缸[CTMA-16x25-S-CA-SDB]_SDB-1 | cad/大葱收种一体机/不锈钢迷你型CTMA系列气缸[CTMA-16x25-S-CA-SDB]/不锈钢迷你型CTMA系列气缸[CTMA-16x25-S-CA-SDB]_SDB.SLDPRT | 后铰固定架 | True | False
不锈钢迷你型CTMA系列气缸[CTMA-16x25-S-CA-SDB]-4/杆端F-M8X125U-1 | cad/大葱收种一体机/杆端F-M8X125U.SLDPRT | 默认 | True | False
播种部分-1 | cad/大葱收种一体机/播种部分.SLDASM | 默认 | True | False
播种部分-1/Spike Gribe-1 | cad/大葱收种一体机/Spike Gribe.SLDPRT | Default | True | False
播种部分-1/储存箱子-1 | cad/大葱收种一体机/储存箱子.SLDPRT | 默认 | True | False
播种部分-1/储存箱子支撑-1 | cad/大葱收种一体机/储存箱子支撑.SLDPRT | 默认<按加工> | True | False
播种部分-1/固定座-1 | cad/大葱收种一体机/固定座.SLDPRT | 默认 | True | False
播种部分-1/固定座-2 | cad/大葱收种一体机/固定座.SLDPRT | 默认 | True | False
播种部分-1/播苗盘-1 | cad/大葱收种一体机/播苗盘.SLDPRT | 默认 | True | False
播种部分-1/播苗盘-3 | cad/大葱收种一体机/播苗盘.SLDPRT | 默认 | True | False
播种部分-1/气缸座2-1 | cad/大葱收种一体机/气缸座2.SLDPRT | 默认 | True | False
播种部分-1/气缸座2-2 | cad/大葱收种一体机/气缸座2.SLDPRT | 默认 | True | False
播种部分-1/特殊螺钉 小径内六角圆柱头螺钉[PSGS-M8-30-B]-1 | cad/大葱收种一体机/标件/特殊螺钉 小径内六角圆柱头螺钉[PSGS-M8-30-B].SLDPRT | 默认 | True | False
播种部分-1/盘-1 | cad/大葱收种一体机/盘.SLDPRT | 默认 | True | False
播种部分-1/负重轮-1 | cad/大葱收种一体机/负重轮.SLDPRT | 默认 | True | False
播种部分-1/负重轮-4 | cad/大葱收种一体机/负重轮.SLDPRT | 默认 | True | False
播种部分-1/负重轮座-1 | cad/大葱收种一体机/负重轮座.SLDPRT | 默认 | True | False
播种部分-1/负重轮座-4 | cad/大葱收种一体机/负重轮座.SLDPRT | 默认 | True | False
收割部分-1 | cad/大葱收种一体机/收割部分.SLDASM | 默认 | True | False
收割部分-1/GB╱T 6186-2000[2型全金属六角锁紧螺母 9级M6]-1 | cad/大葱收种一体机/标件/GB╱T 6186-2000[2型全金属六角锁紧螺母 9级M6].sldprt | M6 | True | False
收割部分-1/GB╱T 6186-2000[2型全金属六角锁紧螺母 9级M6]-10 | cad/大葱收种一体机/标件/GB╱T 6186-2000[2型全金属六角锁紧螺母 9级M6].sldprt | M6 | True | False
收割部分-1/GB╱T 6186-2000[2型全金属六角锁紧螺母 9级M6]-11 | cad/大葱收种一体机/标件/GB╱T 6186-2000[2型全金属六角锁紧螺母 9级M6].sldprt | M6 | True | False
收割部分-1/GB╱T 6186-2000[2型全金属六角锁紧螺母 9级M6]-12 | cad/大葱收种一体机/标件/GB╱T 6186-2000[2型全金属六角锁紧螺母 9级M6].sldprt | M6 | True | False
收割部分-1/GB╱T 6186-2000[2型全金属六角锁紧螺母 9级M6]-2 | cad/大葱收种一体机/标件/GB╱T 6186-2000[2型全金属六角锁紧螺母 9级M6].sldprt | M6 | True | False
收割部分-1/GB╱T 6186-2000[2型全金属六角锁紧螺母 9级M6]-3 | cad/大葱收种一体机/标件/GB╱T 6186-2000[2型全金属六角锁紧螺母 9级M6].sldprt | M6 | True | False
收割部分-1/GB╱T 6186-2000[2型全金属六角锁紧螺母 9级M6]-4 | cad/大葱收种一体机/标件/GB╱T 6186-2000[2型全金属六角锁紧螺母 9级M6].sldprt | M6 | True | False
收割部分-1/GB╱T 6186-2000[2型全金属六角锁紧螺母 9级M6]-9 | cad/大葱收种一体机/标件/GB╱T 6186-2000[2型全金属六角锁紧螺母 9级M6].sldprt | M6 | True | False
收割部分-1/GB╱T 70.2-2015[内六角平圆头螺钉M4×12]-1 | cad/大葱收种一体机/标件/GB╱T 70.2-2015[内六角平圆头螺钉M4×12].sldprt | M4×12 | True | False
收割部分-1/GB╱T 70.2-2015[内六角平圆头螺钉M4×12]-10 | cad/大葱收种一体机/标件/GB╱T 70.2-2015[内六角平圆头螺钉M4×12].sldprt | M4×12 | True | False
收割部分-1/GB╱T 70.2-2015[内六角平圆头螺钉M4×12]-11 | cad/大葱收种一体机/标件/GB╱T 70.2-2015[内六角平圆头螺钉M4×12].sldprt | M4×12 | True | False
收割部分-1/GB╱T 70.2-2015[内六角平圆头螺钉M4×12]-12 | cad/大葱收种一体机/标件/GB╱T 70.2-2015[内六角平圆头螺钉M4×12].sldprt | M4×12 | True | False
收割部分-1/GB╱T 70.2-2015[内六角平圆头螺钉M4×12]-2 | cad/大葱收种一体机/标件/GB╱T 70.2-2015[内六角平圆头螺钉M4×12].sldprt | M4×12 | True | False
收割部分-1/GB╱T 70.2-2015[内六角平圆头螺钉M4×12]-3 | cad/大葱收种一体机/标件/GB╱T 70.2-2015[内六角平圆头螺钉M4×12].sldprt | M4×12 | True | False
收割部分-1/GB╱T 70.2-2015[内六角平圆头螺钉M4×12]-4 | cad/大葱收种一体机/标件/GB╱T 70.2-2015[内六角平圆头螺钉M4×12].sldprt | M4×12 | True | False
收割部分-1/GB╱T 70.2-2015[内六角平圆头螺钉M4×12]-9 | cad/大葱收种一体机/标件/GB╱T 70.2-2015[内六角平圆头螺钉M4×12].sldprt | M4×12 | True | False
收割部分-1/传送带轴固定座-1 | cad/大葱收种一体机/传送带轴固定座.SLDPRT | 默认 | True | False
收割部分-1/传送带轴固定座-2 | cad/大葱收种一体机/传送带轴固定座.SLDPRT | 默认 | True | False
收割部分-1/传送带轴固定座-5 | cad/大葱收种一体机/传送带轴固定座.SLDPRT | 默认 | True | False
收割部分-1/传送带轴固定座-6 | cad/大葱收种一体机/传送带轴固定座.SLDPRT | 默认 | True | False
收割部分-1/传送带轴固定调节座-1 | cad/大葱收种一体机/传送带轴固定调节座.SLDPRT | 默认 | True | False
收割部分-1/传送带轴固定调节座-3 | cad/大葱收种一体机/传送带轴固定调节座.SLDPRT | 默认 | True | False
收割部分-1/传送带轴固定调节电机座-1 | cad/大葱收种一体机/传送带轴固定调节电机座.SLDPRT | 默认 | True | False
收割部分-1/传送带轴固定调节电机座-3 | cad/大葱收种一体机/传送带轴固定调节电机座.SLDPRT | 默认 | True | False
收割部分-1/扶葱-1 | cad/大葱收种一体机/扶葱.SLDPRT | 默认 | True | False
收割部分-1/松土型材支架-1 | cad/大葱收种一体机/松土型材支架.SLDPRT | 默认 | True | False
收割部分-1/松土型材支架-2 | cad/大葱收种一体机/松土型材支架.SLDPRT | 默认 | True | False
收割部分-1/松土型材支架2-1 | cad/大葱收种一体机/松土型材支架2.SLDPRT | 默认 | True | False
收割部分-1/松土型材支架2-2 | cad/大葱收种一体机/松土型材支架2.SLDPRT | 默认 | True | False
收割部分-1/松土铲刀-1 | cad/大葱收种一体机/松土铲刀.SLDPRT | 默认 | True | False
收割部分-1/松土铲刀固定-1 | cad/大葱收种一体机/松土铲刀固定.SLDPRT | 默认 | True | False
收割部分-1/松土铲刀固定-3 | cad/大葱收种一体机/松土铲刀固定.SLDPRT | 默认 | True | False
收割部分-1/松土铲刀固定-4 | cad/大葱收种一体机/松土铲刀固定.SLDPRT | 默认 | True | False
收割部分-1/松土铲刀固定-5 | cad/大葱收种一体机/松土铲刀固定.SLDPRT | 默认 | True | False
收割部分-1/气缸座 3-1 | cad/大葱收种一体机/气缸座 3.SLDPRT | 默认 | True | False
收割部分-1/气缸座 3-2 | cad/大葱收种一体机/气缸座 3.SLDPRT | 默认 | True | False
收割部分-1/气缸座-1 | cad/大葱收种一体机/气缸座.SLDPRT | 默认 | True | False
收割部分-1/气缸座-2 | cad/大葱收种一体机/气缸座.SLDPRT | 默认 | True | False
收割部分-1/活动铰链[CT-20-2020].step-10 | cad/大葱收种一体机/标件/活动铰链[CT-20-2020].step.SLDASM | 默认 | True | False
收割部分-1/活动铰链[CT-20-2020].step-10/_CT1-20-2020.step-1 | cad/大葱收种一体机/_CT1-20-2020.step.SLDPRT | 默认 | True | False
收割部分-1/活动铰链[CT-20-2020].step-10/_CT2-20-2020.step-1 | cad/大葱收种一体机/_CT2-20-2020.step.SLDPRT | 默认 | True | False
收割部分-1/活动铰链[CT-20-2020].step-11 | cad/大葱收种一体机/标件/活动铰链[CT-20-2020].step.SLDASM | 默认 | True | False
收割部分-1/活动铰链[CT-20-2020].step-11/_CT1-20-2020.step-1 | cad/大葱收种一体机/_CT1-20-2020.step.SLDPRT | 默认 | True | False
收割部分-1/活动铰链[CT-20-2020].step-11/_CT2-20-2020.step-1 | cad/大葱收种一体机/_CT2-20-2020.step.SLDPRT | 默认 | True | False
收割部分-1/活动铰链[CT-20-2020].step-12 | cad/大葱收种一体机/标件/活动铰链[CT-20-2020].step.SLDASM | 默认 | True | False
收割部分-1/活动铰链[CT-20-2020].step-12/_CT1-20-2020.step-1 | cad/大葱收种一体机/_CT1-20-2020.step.SLDPRT | 默认 | True | False
收割部分-1/活动铰链[CT-20-2020].step-12/_CT2-20-2020.step-1 | cad/大葱收种一体机/_CT2-20-2020.step.SLDPRT | 默认 | True | False
收割部分-1/活动铰链[CT-20-2020].step-15 | cad/大葱收种一体机/标件/活动铰链[CT-20-2020].step.SLDASM | 默认 | True | False
收割部分-1/活动铰链[CT-20-2020].step-15/_CT1-20-2020.step-1 | cad/大葱收种一体机/_CT1-20-2020.step.SLDPRT | 默认 | True | False
收割部分-1/活动铰链[CT-20-2020].step-15/_CT2-20-2020.step-1 | cad/大葱收种一体机/_CT2-20-2020.step.SLDPRT | 默认 | True | False
收割部分-1/活动铰链[CT-20-2020].step-16 | cad/大葱收种一体机/标件/活动铰链[CT-20-2020].step.SLDASM | 默认 | True | False
收割部分-1/活动铰链[CT-20-2020].step-16/_CT1-20-2020.step-1 | cad/大葱收种一体机/_CT1-20-2020.step.SLDPRT | 默认 | True | False
收割部分-1/活动铰链[CT-20-2020].step-16/_CT2-20-2020.step-1 | cad/大葱收种一体机/_CT2-20-2020.step.SLDPRT | 默认 | True | False
收割部分-1/活动铰链[CT-20-2020].step-25 | cad/大葱收种一体机/标件/活动铰链[CT-20-2020].step.SLDASM | 默认 | True | False
收割部分-1/活动铰链[CT-20-2020].step-25/_CT1-20-2020.step-1 | cad/大葱收种一体机/_CT1-20-2020.step.SLDPRT | 默认 | True | False
收割部分-1/活动铰链[CT-20-2020].step-25/_CT2-20-2020.step-1 | cad/大葱收种一体机/_CT2-20-2020.step.SLDPRT | 默认 | True | False
收割部分-1/活动铰链[CT-20-2020].step-26 | cad/大葱收种一体机/标件/活动铰链[CT-20-2020].step.SLDASM | 默认 | True | False
收割部分-1/活动铰链[CT-20-2020].step-26/_CT1-20-2020.step-1 | cad/大葱收种一体机/_CT1-20-2020.step.SLDPRT | 默认 | True | False
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

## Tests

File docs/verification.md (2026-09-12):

# 发布核验记录 / Publication verification

核验日期 / Inspection date: **2026-09-12**

## 文件完整性 / File integrity

- 用户提供的模型目录共 217 个文件，合计 221,436,406 字节。发布副本逐文件 SHA-256 与源文件及首次清单一致。
- 217 supplied CAD files total 221,436,406 bytes. SHA-256 checks of the publication copy match the source files and the initial manifest for every file.
- 全部模型原文件名和内部目录保留；未重新保存原生 CAD 或重新生成 STEP。答辩 PPT 不在仓库内。
- All original model filenames and internal directories are preserved. Native CAD was not resaved and STEP files were not regenerated. The presentation is excluded.
- [model-inventory.csv](model-inventory.csv) 记录路径、类型、大小及哈希；[SHA256SUMS.txt](SHA256SUMS.txt) 为完整模型校验清单。
- The inventory records path, type, size and hash. The checksum file covers every supplied CAD file.

## CAD 查看 / CAD inspection

| 检查 / Check | 结果 / Result |
| --- | --- |
| 软件 / Application | SOLIDWORKS 2025 SP3.0，API revision 33.3.0 |
| 查看方式 / Viewing | 发布副本设为只读，OpenDoc6 使用 Silent + ReadOnly；激活视图时明确不重建 / Read-only copy; Silent + ReadOnly opening; activation without rebuild |
| 原生模型直接查看并导图 / Native models viewed and illustrated | 总装、收割、播种、翻土、车架、张紧子装配 / Overall assembly, harvesting, planting, soil working, chassis and tensioner |
| 总装组件 / Main-assembly instances | 346；GetSuppression 均为 2（完全解析）/ All returned state 2 (fully resolved) |
| 虚拟零件 / Virtual part | 1 个内嵌零件，2 个实例 / One embedded part, two instances |
| 总装依赖 / Main-assembly dependencies | 67 项：66 个包内外部文件 + 1 个内嵌虚拟零件 / 66 in-package external files plus one embedded virtual part |
| 全部装配与图纸的引用检查 / All assembly/drawing dependencies | 18 个装配体 + 3 张图纸均读取依赖 / Dependencies read for all 18 assemblies and 3 drawings |
| 历史引用缺口 / Historical gaps | 2 张工程图、8 个镜向铰链装配；合计 4 个不同的缺失文件名 / Two drawings and eight mirrored-hinge assemblies; four distinct missing filenames |
| 模型内容 / CAD content | 源文件与发布副本全部哈希一致 / All source and publication hashes match |

详细清单：[总装组件实例 / Main assembly instances](assembly-components.csv)、[装配与工程图依赖 / Assembly and drawing dependencies](dependency-audit.json)。组件清单是当前配置的实例导出，不是已经完成采购、加工或成本核算的 BOM。

The component list is an instance export for the inspected configuration, not a procurement, manufacturing or costed BOM.

## 本次未验证 / Not verified in this release

未对 217 个文件逐一完成图形与几何质量验收，也未进行全配置遍历、强制重建、配合修复、干涉检测、运动/动力学仿真、有限元分析、完整材料与公差审核、制造工艺验证或田间试验。当前加载成功不能替代这些工程验证。未对 STEP 与原生模型做逐实体一致性比对；另外两张历史工程图不能凭引用清单声称已能完整重建。

This release does not individually certify the geometry of all 217 files, traverse every configuration, force a rebuild, repair mates, check interference, perform motion/dynamic simulation or FEA, audit all materials and tolerances, validate manufacturing processes or conduct field tests. Successful loading is not a substitute for those checks. STEP/native entity equivalence was not tested, and the two historical drawings are not certified to rebuild completely.

## API 判据来源 / API reference

- [Component resolution states](https://help.solidworks.com/2023/English/api/swconst/SolidWorks.Interop.swconst~SolidWorks.Interop.swconst.swComponentSuppressionState_e.html)
- [Document dependencies](https://help.solidworks.com/2019/english/api/sldworksapi/SOLIDWORKS.Interop.sldworks~SOLIDWORKS.Interop.sldworks.ISldWorks~GetDocumentDependencies2.html)
- [View bitmap export](https://help.solidworks.com/2021/English/api/sldworksapi/SolidWorks.Interop.sldworks~SolidWorks.Interop.sldworks.IModelDoc2~SaveBMP.html)
